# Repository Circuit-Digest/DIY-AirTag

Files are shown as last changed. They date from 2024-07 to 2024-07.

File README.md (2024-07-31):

# DIY AirTag: Never Lose Your Keys Again!
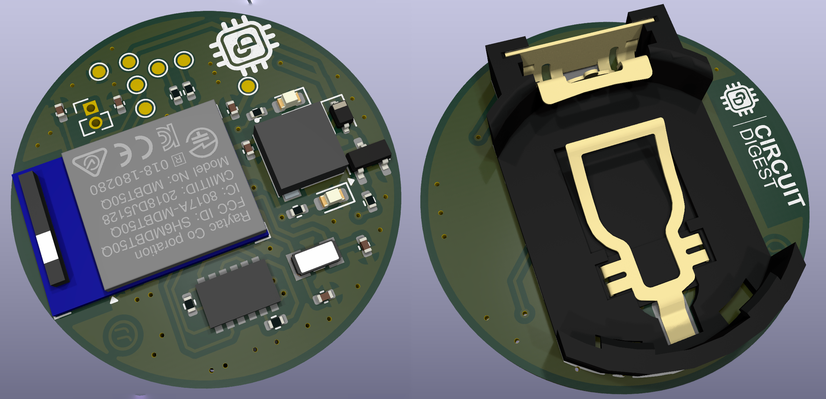
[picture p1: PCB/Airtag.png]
image_tooltip

We all know that there is nothing more infuriating than forgetting where we placed something important or misplaced things. Losing your keys, wallet, or other valuable items can be a frustrating experience. Apple recognised this common problem and introduced the AirTag, a small, Bluetooth-enabled device that helps you keep track of your belongings. By attaching an AirTag to your items, you can easily locate them using the "Find My" app on your iPhone. The AirTag sends a secure Bluetooth signal that nearby devices in the Find My network can detect, allowing you to see the item's location on a map. Inspired by the functionality and usefulness of Apple's AirTag, we created a DIY solution that brings similar benefits with a personal touch. This project involves creating your own Bluetooth Low Energy (BLE) air tag/key finder that will help you keep your important things safe. The heart of this project is an MDBT50Q-1MV2 BLE  module from Raytac featuring an nRF52840, an ultra low power BLE SoC from Nordic with a 32-bit ARM Cortex-M4 core running at 64MHz. An ADXL345 3-axis accelerometer from Analog devices is also included in the circuit to detect movement. Multiple LEDs and an active buzzer are provided for visual and audible indications. The whole circuit is powered by a 3V CR2032 lithium battery. The key finder function can be used to find the Airtag which the Airtag will output a loud alarm along with LED indications, which makes it easier to find it in both bright and dark environments. With loss prevention mode enabled the Airtag will sound the Alarm and LED indications as soon as the Airtag is disconnected from the smartphone.

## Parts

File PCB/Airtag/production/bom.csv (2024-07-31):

Designator | Footprint | Quantity | Value | LCSC Part #
BT1 | BH-74B-5 | 1 | CR2032
BZ1 | SMT0540SR | 1 | SMT-0540-S-R
C1, C2 | 0402 | 2 | 7pF
C3, C4, C5, C6 | 0402 | 4 | 10uF
D1, D2 | 0603 | 2 | LED
D3 | D_SOD-323 | 1 | 1N4148WS
IC1 | LGA14R80P3X6_300X500X100 | 1 | ADXL345BCCZ
J1 | PinHeader_1x02_P1.27mm_Vertical | 1 | NFC ANT
Q1 | SOT-23 | 1 | S8050
R1, R2, R5 | 0402 | 3 | 1k
R3, R4 | 0402 | 2 | 27
R6, R7 | 0402 | 2 | 10k
TP1, TP2, TP3, TP4, TP5, TP6, TP7 | TestPoint_Pad_D1.0mm | 7 | TestPoint
U1 | Raytac_MDBT50Q | 1 | MDBT50Q-1MV2
Y1 | ABS07 | 1 | 32.768KHz

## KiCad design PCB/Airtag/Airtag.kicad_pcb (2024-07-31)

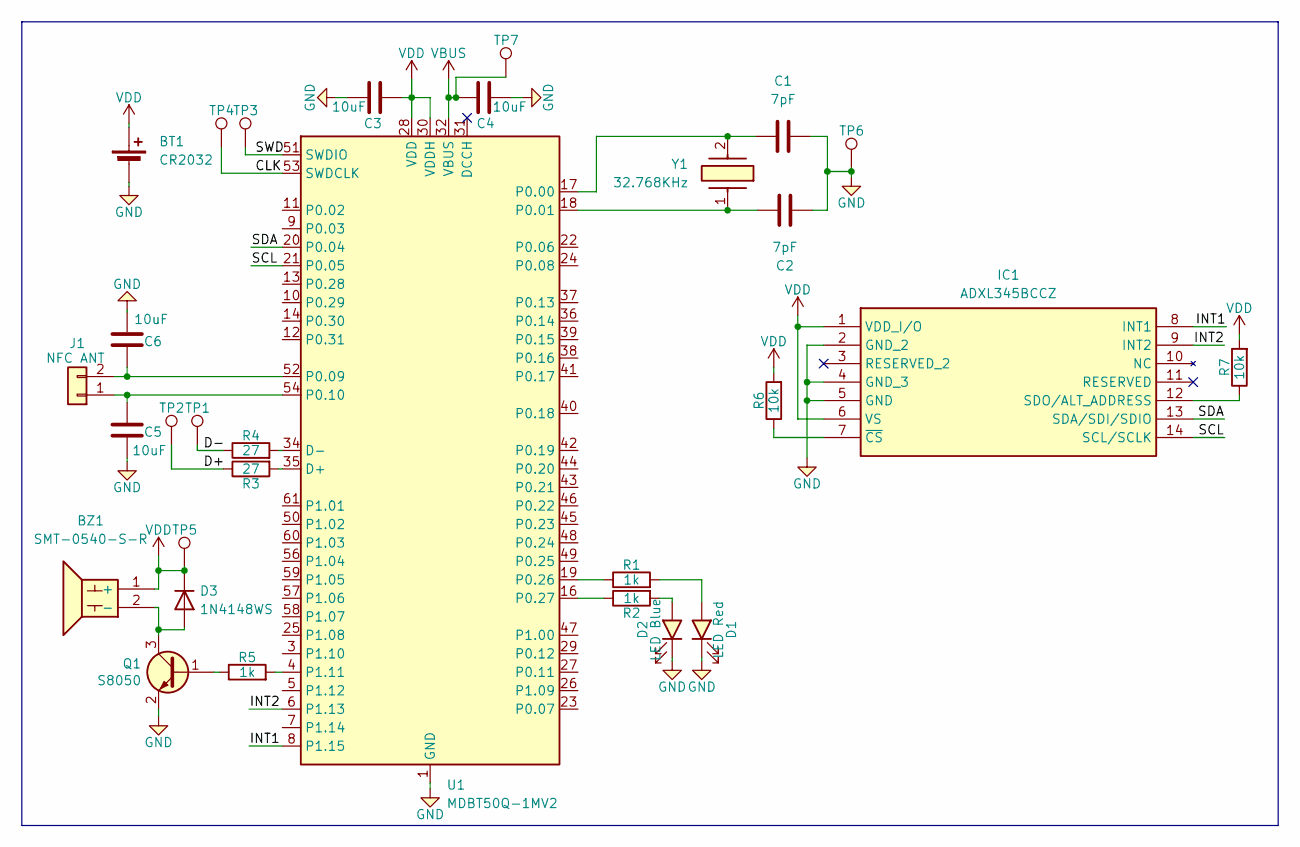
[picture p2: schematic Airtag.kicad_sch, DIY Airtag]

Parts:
BT1: CR2032; BH-74B-5; DigiKey Part Number 2057-BH-74B-5-ND
BZ1: SMT-0540-S-R; SMT0540SR; DigiKey Part Number 668-1060-1-ND
C1, C2: 7pF; C_0402_1005Metric; DigiKey Part Number 490-5878-1-ND
C3, C4, C5, C6: 10uF; C_0402_1005Metric; DigiKey Part Number 490-GRM155R60J106ME05DCT-ND
D1: LED Red; LED_0603_1608Metric; DigiKey Part Number 3147-B1911USD-20D000114U1930CT-ND
D2: LED Blue; LED_0603_1608Metric; DigiKey Part Number 3147-B1911NB--20C005314U1930CT-ND
D3: 1N4148WS; D_SOD-323; DigiKey Part Number 4878-1N4148WSCT-ND
IC1: ADXL345BCCZ; LGA14R80P3X6_300X500X100; DigiKey Part Number 505-ADXL345BCCZ-ND
J1: NFC ANT; PinHeader_1x02_P1.27mm_Vertical
Q1: S8050; SOT-23; DigiKey Part Number MMSS8050-L-TPMSCT-ND
R1, R2, R5: 1k; R_0402_1005Metric; DigiKey Part Number P1.00KLCT-ND
R3, R4: 27; R_0402_1005Metric; DigiKey Part Number P27.0LCT-ND
R6, R7: 10k; R_0402_1005Metric; DigiKey Part Number P10.0KLCT-ND
TP1, TP2, TP3, TP4, TP5, TP6, TP7: TestPoint; TestPoint_Pad_D1.0mm
U1: MDBT50Q-1MV2; Raytac_MDBT50Q; DigiKey Part Number 1597-1678-ND
Y1: 32.768KHz; ABS07; DigiKey Part Number 535-9543-1-ND

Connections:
/CLK: TP4.1, U1.53 (SWDCLK)
/D+: R3.1, TP2.1
/D-: R4.1, TP1.1
/INT1: IC1.8 (INT1), U1.8 (P1.15)
/INT2: IC1.9 (INT2), U1.6 (P1.13)
/SCL: IC1.14 (SCL/SCLK), U1.21 (P0.05)
/SDA: IC1.13 (SDA/SDI/SDIO), U1.20 (P0.04)
/SWD: TP3.1, U1.51 (SWDIO)
GND: BT1.2 (-), C1.2, C2.2, C3.1, C4.1, C5.1, C6.2, D1.1 (K), D2.1 (K), IC1.2 (GND_2), IC1.4 (GND_3), IC1.5 (GND), Q1.2 (B), TP6.1, U1.1 (GND), U1.2 (GND), U1.15 (GND), U1.33 (GND), U1.55 (GND)
unnamed: BZ1.2 (-), D3.2 (A), Q1.3 (C)
unnamed: D1.2 (A), R1.2
unnamed: D2.2 (A), R2.2
unnamed: IC1.12 (SDO/ALT_ADDRESS), R7.1
unnamed: IC1.7 (~CS), R6.1
unnamed: C5.2, J1.1, U1.54 (P0.10)
unnamed: C6.1, J1.2, U1.52 (P0.09)
unnamed: Q1.1 (E), R5.1
unnamed: R3.2, U1.35 (D+)
unnamed: R4.2, U1.34 (D-)
unnamed: C1.1, U1.17 (P0.00), Y1.2
unnamed: C2.1, U1.18 (P0.01), Y1.1
unnamed: R1.1, U1.19 (P0.26)
unnamed: R2.1, U1.16 (P0.27)
unnamed: R5.2, U1.4 (P1.11)
VBUS: C4.2, TP7.1, U1.32 (VBUS)
VDD: BT1.1 (+), BZ1.1 (+), C3.2, D3.1 (K), IC1.1 (VDD_I/O), IC1.6 (VS), R6.2, R7.2, TP5.1, U1.28 (VDD), U1.30 (VDDH)

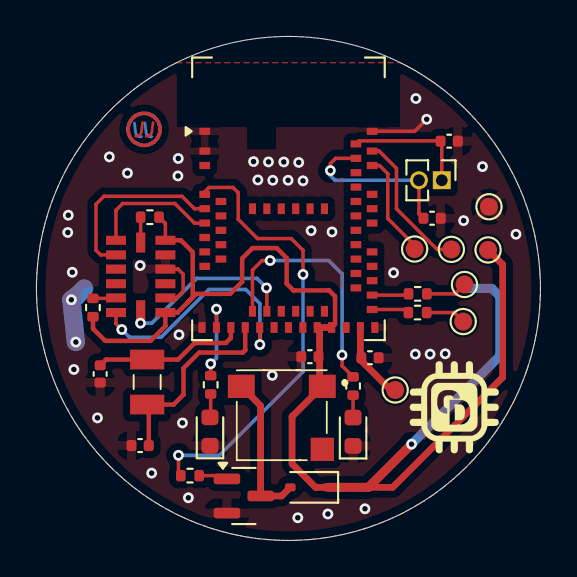
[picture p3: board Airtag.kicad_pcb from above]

Board: 2 copper layers, 28.0 x 28.0 mm, 30 parts (1 on the bottom side), 26 nets.

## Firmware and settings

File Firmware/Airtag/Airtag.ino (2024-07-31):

#include <ArduinoBLE.h>
#include "PlayRtttl.hpp"

const int TONE_PIN = D6;
BLEService keyFinderService("180A");
//BLECharacteristic keyFinderCharacteristic("2A19", BLERead | BLEWrite, 1);
BLECharacteristic alarmControlCharacteristic("2A3F", BLERead | BLEWrite, 1);  // New characteristic to control alarm
BLECharacteristic alarmEnableCharacteristic("2A06", BLERead | BLEWrite, 1);   // New characteristic to enable/disable alarm

char alarmTone[] = "Alarm:d=16,o=5,b=125:c,e,g,c6,e6,g6,c7,e7,g7";

unsigned long previousMillis = 0;  // Stores the last time the LEDs were updated
const long interval = 250;         // Interval at which to blink (milliseconds)

bool isPlayingAlarm = false;
bool ledState = LOW;
bool alarmEnabled = false;  // Flag to enable or disable alarm

void setup() {
  pinMode(P1_11, OUTPUT);
  pinMode(P0_26, OUTPUT);
  pinMode(P0_27, OUTPUT);

  Serial.begin(9600);
  /*
  while (!Serial)
    ;
    */
  if (!BLE.begin()) {
    Serial.println("Starting BLE failed!");
    while (1)
      ;
  }

  BLE.setLocalName("Airtag");
  BLE.setAdvertisedService(keyFinderService);
  //keyFinderService.addCharacteristic(keyFinderCharacteristic);
  keyFinderService.addCharacteristic(alarmControlCharacteristic);  // Add new characteristic
  keyFinderService.addCharacteristic(alarmEnableCharacteristic);   // Add new characteristic
  BLE.addService(keyFinderService);

  //keyFinderCharacteristic.writeValue((uint8_t)0);
  alarmControlCharacteristic.writeValue((uint8_t)0);
  alarmEnableCharacteristic.writeValue((uint8_t)alarmEnabled);  // Set initial alarm enabled state

  BLE.advertise();
  Serial.println("BLE device is now advertising");
  digitalWrite(P0_26, LOW);  // Turn off LEDs
  digitalWrite(P0_27, LOW);
  isPlayingAlarm = false;
}

void loop() {
  BLEDevice central = BLE.central();

  if (central) {
    Serial.print("Connected to central: ");
    Serial.println(central.address());

    digitalWrite(P0_26, LOW);  // Turn off LEDs
    digitalWrite(P0_27, LOW);
    noTone(P1_11);  // Ensure the buzzer is off

    isPlayingAlarm = false;

    while (central.connected()) {
      // Check if alarm control characteristic has been written
      if (alarmControlCharacteristic.written()) {
        uint8_t alarmControlValue = alarmControlCharacteristic.value()[0];
        if (alarmControlValue) {
          // Activate alarm
          isPlayingAlarm = true;
        } else {
          // Deactivate alarm
          isPlayingAlarm = false;
          noTone(TONE_PIN);
          digitalWrite(P0_26, LOW);
          digitalWrite(P0_27, LOW);
        }
      }

      // Check if alarm enable characteristic has been written
      if (alarmEnableCharacteristic.written()) {
        alarmEnabled = alarmEnableCharacteristic.value()[0];
      }
      if (isPlayingAlarm) {
        unsigned long currentMillis = millis();

        // Flash LEDs like a police siren
        if (currentMillis - previousMillis >= interval) {
          previousMillis = currentMillis;
          ledState = !ledState;  // Toggle the LED state
          digitalWrite(P0_26, ledState ? LOW : HIGH);
          digitalWrite(P0_27, ledState ? HIGH : LOW);
        }

        // Update the alarm tone continuously
        if (!updatePlayRtttl()) {
          // Restart the tone if it has finished
          startPlayRtttl(TONE_PIN, alarmTone);
        }
      } else {
        unsigned long currentTime = millis();
        if (ledState && currentTime - previousMillis >= 250) {
          previousMillis = currentTime;
          ledState = LOW;  // Turn off LED
          digitalWrite(P0_26, LOW);
        }
        if (currentTime - previousMillis >= 3000) {
          previousMillis = currentTime;
          ledState = HIGH;  // Turn on LED
          digitalWrite(P0_26, HIGH);
        }
      }
    }

    Serial.print("Disconnected from central: ");
    Serial.println(central.address());

    // Reset state for disconnection

    // Start playing the alarm tone if alarm is enabled
    if (alarmEnabled) {
      startPlayRtttl(TONE_PIN, alarmTone);
      isPlayingAlarm = true;
      previousMillis = 0;
    }
  }

  if (isPlayingAlarm) {
    unsigned long currentMillis = millis();

    // Flash LEDs like a police siren
    if (currentMillis - previousMillis >= interval) {
      previousMillis = currentMillis;
      ledState = !ledState;  // Toggle the LED state
      digitalWrite(P0_26, ledState ? LOW : HIGH);
      digitalWrite(P0_27, ledState ? HIGH : LOW);
    }

    // Update the alarm tone continuously
    if (!updatePlayRtttl()) {
      // Restart the tone if it has finished
      startPlayRtttl(TONE_PIN, alarmTone);
    }
  }
  else
  {
            unsigned long currentTime = millis();
        if (ledState && currentTime - previousMillis >= 250) {
          previousMillis = currentTime;
          ledState = LOW;  // Turn off LED
          digitalWrite(P0_27, LOW);
        }
        if (currentTime - previousMillis >= 3000) {
          previousMillis = currentTime;
          ledState = HIGH;  // Turn on LED
          digitalWrite(P0_27, HIGH);
        }
  }

  delay(10);  // Small delay to prevent excessive CPU usage
}
